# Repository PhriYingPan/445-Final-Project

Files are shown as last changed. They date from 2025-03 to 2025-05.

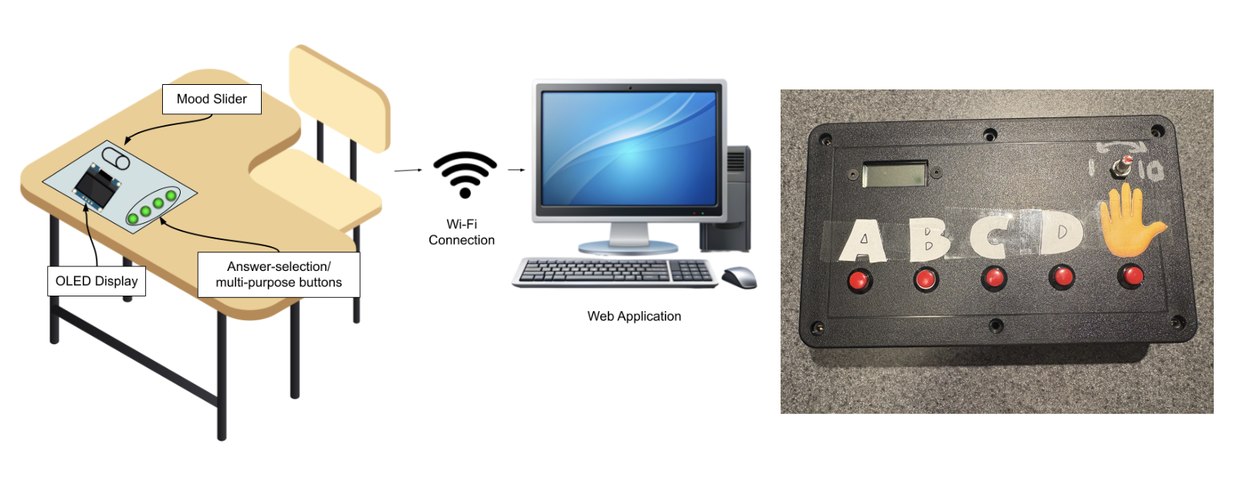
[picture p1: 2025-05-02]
visual_aid.png

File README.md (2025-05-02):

# Desk Aid Learning Device 

### Team Members

- [Aidan Johnston](https://github.com/AidanJ16)
- [Conan Pan](https://github.com/PhriYingPan)
- [Ethan Ge](https://github.com/ethange2)

## 1.1 Problem

In recent years, there has been a growing trend of integrating technology into schools. This trend has been accelerated by the lasting impacts of the Covid-19 pandemic and the continuous advancements in digital devices and tools. Schools across the nation have adopted computers, tablets, and virtual learning platforms to enhance education and increase accessibility in the pursuit of modernizing the classroom. While these technologies offer incredible benefits, they also introduce challenges, particularly in elementary school classrooms. 

One of the most critical problems is the effect screen time is having on students. By incorporating technological devices in classrooms, students are spreading prolonged periods interacting with screens. Studies have begun to highlight how this excessive screen time can lead to a severe lack of social skills, shorter attention spans, and higher frequencies of disruptions. These trends contribute to a less effective and unhealthy learning environment. Furthermore, studies are exploring connections between prolonged exposure to screens and decreases in mental and physical well-being. Therefore, in the pursuit of generating a more social, engaging, and nurturing environment for young students we propose the desk learning aid device.

## 1.2 Solution

The desk learning aid device will function through various buttons and a scroller connected to a customized PCB device. These buttons and the scroller will correspond to responding to polls/questions, comprehension checks, asking questions, and more. The device will communicate to an application that can be monitored by the teacher where they will receive real-time feedback. The teacher can have a better understanding of the student’s comprehension levels and be able to properly cater towards providing the students the most effective lesson. The purpose of this device would be to provide a cost-effective solution that can be set up at each student’s desk to promote a stronger and healthier learning environment for students. This differs from other options on the market due to easier set up because other options require you to create a question in order to receive a response, however, our device allows for many passive inputs including comprehension and other urgent needs. In addition, other portable solutions require students to buy each device individually costing them hundreds of dollars, but our solution only requires the purchase of a reusable RFID keycard that is cheap and easy to use.

# Visual Aid 
Screenshot 2025-05-02 at 2 36 59 PM

# Results

 - [Demo Video](https://drive.google.com/file/d/13fJDIUi9QKVj2l2KASiBSuiVs_a9EkWj/view?usp=sharing)
 - [Presentation](https://github.com/user-attachments/files/20017662/Desk.Aid.Learning.Device.Team.27.pptx)
 - [Design Document](https://github.com/user-attachments/files/20017668/445.Design.Document.3.pdf)

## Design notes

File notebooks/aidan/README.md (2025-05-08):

# Aidan Johnston's Lab Notebook – Desk Learning Aid Device

This notebook documents the comprehensive design, development, testing, and firmware implementation for the Desk Learning Aid Device. It particularly highlights my contributions to the customized PCB and subsystem integration.

---

## 2025-02-01 – Initial Project Direction

**Objectives:**

* Discussed the core project idea and goals with teammates and our TA, Kaiwen Cao.
* Explored engagement mechanisms suitable for classroom environments that avoid excessive screen time.

**Progress:**

* Proposed using a physical interaction system incorporating RFID-based student identification, button-based input, and a rotary encoder or potentiometer scroller.
* Envisioned a backend system supported by Firebase to relay data to a real-time web dashboard accessible to teachers.
* Sketched an initial block diagram representing all subsystems (power, microcontroller, interface, input, and RFID).

---

## 2025-02-14 – Finalize Project

**Objectives:**

* Solidify the overall architecture and prepare for the proposal review.

**Progress:**

* Finalized a refined block diagram detailing subsystem interactions.
* Designed initial device enclosures and mounting plans for discussion with the Machine Shop.
* Scheduled zoom meetings with elementary school teachers to ensure project alignment with classroom needs.
* Began outlining our project proposal for review by course instructors and TAs.

---

## 2025-02-23 – Initial PCB Design Part 1

**Objectives:**

* Begin translating conceptual design into manufacturable electronic schematics.

**Progress:**

* Created a rough draft schematic in KiCad featuring major components: ESP32-S3, push buttons, RFID, voltage regulators, and display interface.
* Assigned preliminary footprints to each component, focusing on pin mapping and layout constraints.

---

## 2025-03-05 – Initial PCB Design Part 2

**Objectives:**

* Convert schematic to a routed PCB design and initiate documentation.

**Progress:**

* Structured the PCB by subsystem (power, input, interface, RFID, microcontroller), allowing for intuitive routing.
* Assigned logical labels, visibility settings, and ground stitching to reduce EMI.
* Helped draft the design documentation section related to PCB layout, component selection, and routing decisions.

---

## 2025-03-13 – Initial PCB Design Part 3

**Objectives:**

* Submit the initial board to PCBWay.

**Progress:**

* Used KiCad's Design Rule Checker to identify and correct errors.
* Submitted and passed PCBWay's manufacturing audit.
* Submitted the design to our TA as apart of the Second Round Orders.

---

## 2025-03-24 – Updated PCB Design Part 1

**Objectives:**

* Evaluate prior board and fix discovered issues.

**Challenges:**

* Incorrect footprint for buck-boost converter (TPS63001).
* Programming circuit for ESP32-S3 not compatible with UART flashing.
* Incorrect footprints for push buttons, inverters, and LCD connector.

**Solutions:**

* Corrected all footprints by referencing datasheets and comparing to KiCad libraries.
* Revised programming method to use USB-to-UART dongle with GND, TX, RX, DTR, RTS lines.
* Rechecked layout and connections for consistency and ease of access.

---

## 2025-03-31 – Updated PCB Design Part 2

**Objectives:**

* Submit improved board design.

**Progress:**

* Rerouted traces and updated board labeling.
* Verified footprint clearances and pad sizes.
* Used KiCad's Design Rule Checker to identify and correct errors.
* Submitted and passed PCBWay's manufacturing audit.
* Submitted the design to our TA as apart of the Third Round Orders.

---

## 2025-04-17 – Hardware Testing

**Objectives:**

* Validate the power subsystem and ESP32 flashing.

**Progress:**

* Measured 3.27V at ESP32 input pin (target: 3.3V).
* Identified error in design: resistor R13 (pull-down) interfered with programming, removed it to enable successful flashing.

---

## 2025-04-29 – Software Testing

**Objectives:**

* Program LCD to verify interface subsystem.

**Progress:**

* Initial attempts to display characters failed.
* Identified reversed SPI pin assignments to LCD: MOSI needed to connect to SID, and MISO to SOD.
* Recognized need for external RST circuit for reliable LCD initialization.

---
## Verification Procedures

**1. DRC Testing**

* All boards verified using KiCad’s DRC.
* Ensured clearance, trace width, and via rules met manufacturing constraints.

**2. Continuity Testing**

* Verified pin-to-pin connections and ground continuity.
* Used multimeter beep function across all critical signal lines.

**3. Power Integrity Test**

* Verified output voltages at ESP32 (3.27V), LCD, and RFID reader.
* Measured battery charge and boost output stability under load.

**4. Boot and Flash Test**

* Helped successfully flash test program using esptool.py.

**5. Input Test**

* Button presses triggered correct GPIO interrupts.
* Potentiometer yielded stable ADC values.

---

## Bibliographic References

1. Espressif Systems. (2023). *ESP32-S3-WROOM-1 & ESP32-S3-WROOM-1U Datasheet*.
2. Firebase. (2024). *Realtime Database Documentation*.
3. ELECTRONIC ASSEMBLY GmbH. (n.d.). *DOGS104E Graphic Display Module*.
4. Texas Instruments. (2008). *TPS63000 High-Efficiency Buck-Boost Converter Datasheet*.
5. TOPPOWER. (2023). *TP4057 Battery Charging and Protection IC Datasheet*.
6. Texas Instruments. (2002). *SN74LS05 Hex Inverter Datasheet*.
7. NXP Semiconductors. (2018). *PN512 NFC Reader IC Datasheet*.
8. Adafruit. (n.d.). *Push Button #492*.
9. Bourns Inc. (2020). *PDB181 Series Potentiometer Datasheet*.
10. IEEE. (2023). *IEEE Code of Ethics*.
11. U8G2 Library Documentation. (2024). *Monochrome Graphics Library for Embedded Devices*.

---

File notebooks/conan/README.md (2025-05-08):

# Conan Pan's Lab Notebook – Desk Learning Aid Device

This notebook documents the design, development, and testing efforts for the Desk Learning Aid Device, specifically focusing on the web application and firmware components I was responsible for.

---

## 2025-02-01 – Initial Project Direction

**Objectives:**
- Discussed core project idea with teammates and TA.
- Brainstormed solutions for capturing student engagement without screens.

**Progress:**
- Proposed idea of combining physical desk input (RFID, buttons, scroller) with a teacher-facing web dashboard.
- Identified potential microcontroller (ESP32-S3) and real-time database (Firebase).
- Sketched initial system block diagram.

---

## 2025-02-14 – WiFi Communication Plan

**Objectives:**
- Finalize communication protocol between ESP32 and Web App.

**Progress:**
- Decided to send data from ESP32 → Web App via Wifi, with ESP32 acting as Wifi server.
- Drafted JSON data schema:
```json
{
  "timestamp": 1712159000000,
  "rfid": "04A3C2",
  "emotion": 7,
  "selectedAnswer": "B",
  "question": "Which fraction is smallest?",
  "subject": "Math",
  "correctAnswer": "C",
  "isCorrect": false
}
```

---

## 2025-03-05 – Breadboard Prototype

**Objectives:**
- Demonstrate basic functionality with ESP32-S3 on breadboard.

**Progress:**
- Wired 5 push buttons, 1 rotary scroller, RFID reader.
- Developed C firmware (`hello_world_main.c`) to:
  - Debounce button presses.
  - Sample potentiometer input via ADC1_CH8.
  - Send responses to Firebase via HTTPS.
- Verified WiFi round-trip latency under 100ms and analog scaling of emotion (1–10).

---

## 2025-03-13 – Dashboard Development

**Objectives:**
- Build interactive frontend dashboard for teachers.

**Progress:**
- Implemented `StudentDashboard.jsx` in React:
  - Displays correctness history, emotion bar, and raise-hand notifications.
  - Allows teacher to push prompts to Firebase.
  - Visualizes subject performance using Chart.js.
- Integrated Firebase Realtime Database and onValue listeners.

Screenshot 2025-05-01 at 3 58 56 PM

Screenshot 2025-05-01 at 3 59 00 PM

Screenshot 2025-05-01 at 4 01 00 PM

---

## 2025-03-24 – Tolerance and Signal Analysis

**Objectives:**
- Evaluate WiFi reliability in classroom conditions.

**Equations:**
Using log-distance path loss model:

PL(d) = PL(d₀) + 10n log₁₀(d/d₀)

PL(10 m) = 40 dB + 10 × 2.7 × log₁₀(10) = 67 dB

ESP32 TX Power: +4 dBm  
WiFi Sensitivity: –90 dBm  
→ Received power = –63 dBm → Link margin = 27 dB

**Result:** WiFi communication is reliable across a 10-meter classroom with expected margin.

---

## 2025-04-29 – Final Integration and Debugging

**Objectives:**
- Complete testing loop from physical input to UI.
- Fix Firebase timestamp issues.

**Progress:**
- Verified timestamps now use `time(NULL) * 1000` for accurate ms precision.
- Fixed JSON encoding and logging in Firebase.
- Coordinated with hardware team to validate ESP32 behavior on PCB power-up.

Screenshot 2025-05-01 at 4 06 28 PM

Screenshot 2025-05-01 at 4 23 56 PM

**Remaining Tasks:**
- Final UI polish (labels, error states).
- Secure Firebase rules and access tokens.
- Conduct classroom-scale demo.

---

## Bibliographic References

1. [ESP32-S3-WROOM Datasheet](https://www.espressif.com/sites/default/files/documentation/esp32-s3-wroom-1_datasheet_en.pdf)  
2. [Firebase Realtime Database Docs](https://firebase.google.com/docs/database)  
3. [Chart.js Documentation](https://www.chartjs.org/docs/)  
4. [Adafruit Push Button #492](https://www.adafruit.com/product/492)  
5. [Bourns PDB181 Datasheet](https://www.bourns.com/docs/Product-Datasheets/pdb181.pdf)

---

## Notes

- All application code (ESP32 firmware and web dashboard) was written by me.
- GitHub repo includes full commit history and test data.

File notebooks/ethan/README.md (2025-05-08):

# Ethan Ge's Lab Notebook – Desk Learning Aid Device

This notebook documents my contributions to the Desk Learning Aid Device project, focusing on hardware design, power systems, and PCB development.

---

## 2025-02-01– Initial Hardware Architecture

**Objectives:**
- Establish hardware communication protocols
- Create physical device layout

**Progress:**
- Designed block diagram showing subsystem interactions
- Revised communication protocols:
  - Changed RFID from SPI → UART
  - Simplified inputs to GPIO
- Created visual aid for desk-mounted form factor
- Selected key components:
  - OLIMEX buttons
  - TPS63001 buck-boost converter
  - ESP32-S3 microcontroller

Block Diagram

---

## 2025-02-14– Power System Design

**Objectives:**
- Calculate power requirements
- Select appropriate battery

**Calculations:**
```
Total Power Draw = (3.3V * 100mA) / 90% efficiency = 0.36W
Battery Capacity Needed = 0.36W * 8h / 3.7V = 1086mAh
```

**Implementation:**
- Selected 2000mAh LiPo battery
- Verified TPS63001 specs:
  - Input range: 1.8-5.5V
  - Output: 3.3V ±2%
  - Peak efficiency: 96%

**Test Plan:**
| Requirement | Verification Method |
|---|---|
| 8h runtime @ 3.0V+ | Continuous operation test |
| Stable 3.3V output | Variable load testing |

---

## 2025-03-05 – PCB Development

**Objectives:**
- Finalize PCB layout
- Address design flaws

**Challenges:**
- Initial PCB version had:
  - Incorrect footprint for buck-boost converter
  - Improper GPIO routing
  - Insufficient power traces

**Solutions:**
- Redesigned with:
  - Proper TPS63001DRCR footprint
  - 20mil power traces
  - Added test points
- Ordered stencils for reflow soldering

PCB Layout

---

## 2025-03-13 – Hardware Testing

**Objectives:**
- Validate power subsystem
- Test component integration

**Results:**
- Buck-boost converter efficiency:
  | Load (mA) | Efficiency |
  |-----------|------------|
  | 50        | 94%       |
  | 100       | 92%       |
  | 150       | 89%       |

- Battery discharge test:
  - 8h continuous operation
  - Final voltage: 3.27V (meets requirement)
 
Test Results

**Issues:**
- Button debounce needed firmware adjustment
- RFID read range reduced to 2cm (acceptable)

---

## 2025-03-24 – System Integration

**Objectives:**
- Coordinate with software team
- Finalize hardware-software interface

**Progress:**
- Finalized firmware for ESP32
- Verified end-to-end operation:
  - Physical input → ESP32 → Web dashboard
  - Average latency: 120ms

**Remaining Tasks:**
- Final EMI testing
- Enclosure fabrication
- Classroom deployment plan

---

## Bibliographic References

1. [ESP32-S3 Datasheet](https://www.espressif.com/sites/default/files/documentation/esp32-s3_datasheet_en.pdf)
2. [TPS63001 Technical Reference](https://www.ti.com/lit/ds/symlink/tps63001.pdf)
3. [LiPo Battery Characteristics](https://batteryuniversity.com/article/bu-205-types-of-lithium-ion)
4. [PCB Design Guidelines](https://www.analog.com/en/analog-dialogue/articles/pcb-layout-techniques.html)

---

## Notes

- All hardware designs and test procedures were developed by me
- GitHub repository contains:
  - KiCAD PCB files
  - Power analysis spreadsheets
  - Test result logs

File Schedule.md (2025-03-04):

# 445-Final-Project

Schedule: 

Week
Date
Task 
1
2/26 - 3/3
- Finalize architecture & system design (Block Diagram, High-Level Requirements)
- Select and order key components for the first prototype
- Prepare for Design Document submission

2
3/4 - 3/10
- Design Document Due (3/3)
- First Round PCBWay Order (Must Pass Audit by Today, 3/3)
- Start initial breadboard prototyping and circuit validation
- Develop firmware skeleton for microcontroller functionality

3
3/11 - 3/17
- Breadboard Demonstration with Instructor & TA (3/10)
- Test basic component functionality (buttons, RFID reader, OLED display)
- Validate Bluetooth Low Energy (BLE) communication with web app
- Second Round PCBWay Order (Must Pass Audit by Today, 3/10)

4
3/18 - 3/24
No work scheduled

5
3/25 - 3/31
- Refine PCB design and address any issues from breadboard testing
- Test battery power consumption and efficiency
- Start developing microcontroller drivers for all subsystems

6
4/1 - 4/7
- Third Round PCBWay Order (Must Pass Audit by Today, 3/31)
- Individual Progress Reports Due (3/31)
- Assemble first PCB and perform functional testing
- Debug BLE communication and integrate with the web application

7
4/8 - 4/14
- Fourth Round PCBWay Order (Must Pass Audit by Today, 4/7)
- Begin full system integration and initial software debugging
- Conduct power management tests and optimize battery life

8
4/15 - 4/21
- Team Contract Assessment Due (4/14)
- Start testing real-time classroom interactions with the web application
- Optimize PCB and firmware for responsiveness and low latency

9
4/22 - 4/28
- Mock Demo During Weekly TA Meeting
- Verify all high-level requirements are met
- Debug remaining issues in hardware/software integration

10
4/29 - 5/5
- Final Demo with Instructor & TAs (4/28)
- Conduct system-wide performance testing
- Prepare presentation materials for final submission

11
5/6 - 5/12
- Final Presentation with Instructor & TAs (5/5)
- Final Papers Due (5/5)
- Lab Notebook Due (5/5)
- Award Ceremony (5/5)
- Perform final documentation and lab checkout

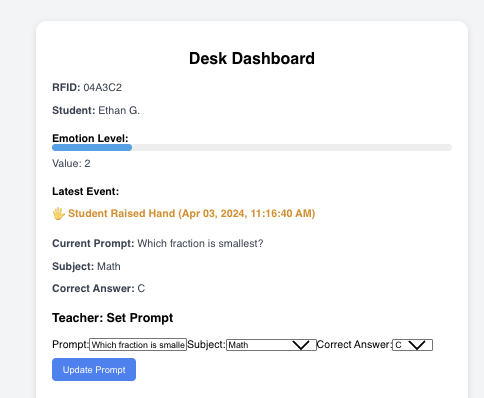
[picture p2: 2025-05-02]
notebooks/conan/dashboard_1.png

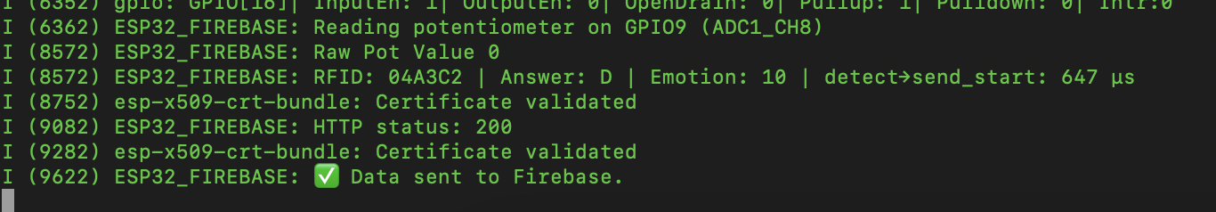
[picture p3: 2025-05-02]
notebooks/conan/button_latency.png

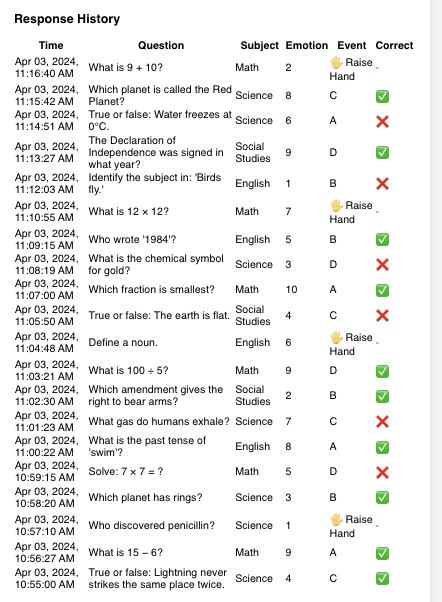
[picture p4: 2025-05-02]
notebooks/conan/dashboard_2.png

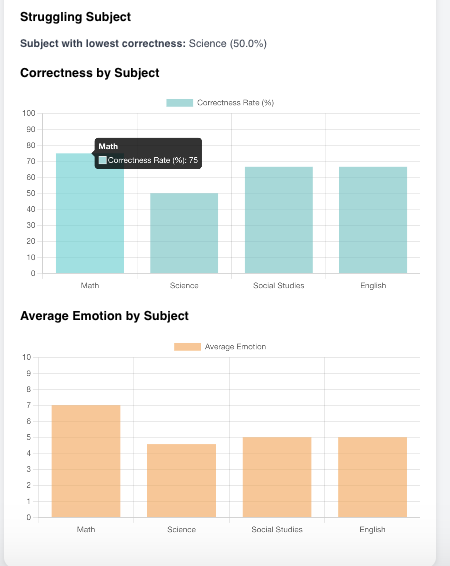
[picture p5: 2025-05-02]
notebooks/conan/dashboard_3.png

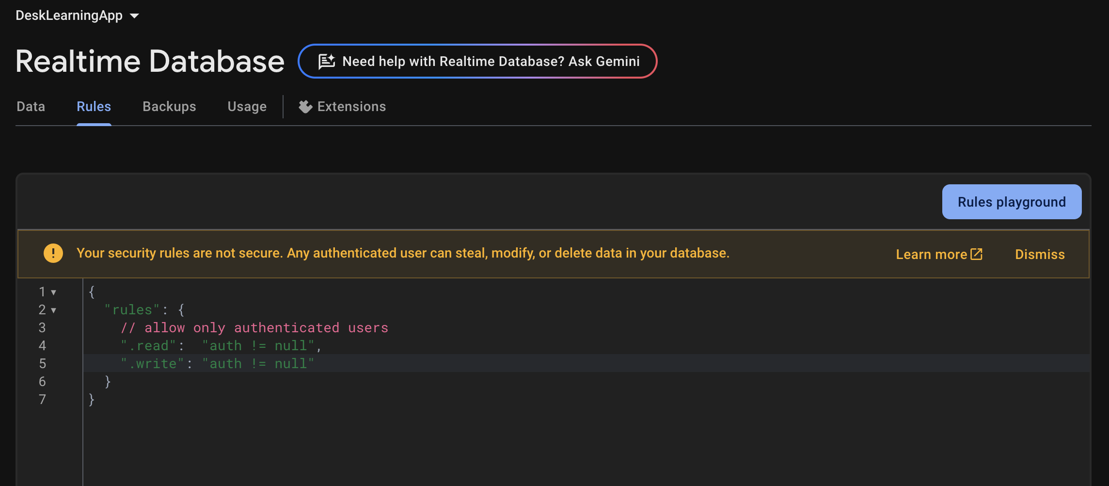
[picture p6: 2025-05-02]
notebooks/conan/firebase_auth.png

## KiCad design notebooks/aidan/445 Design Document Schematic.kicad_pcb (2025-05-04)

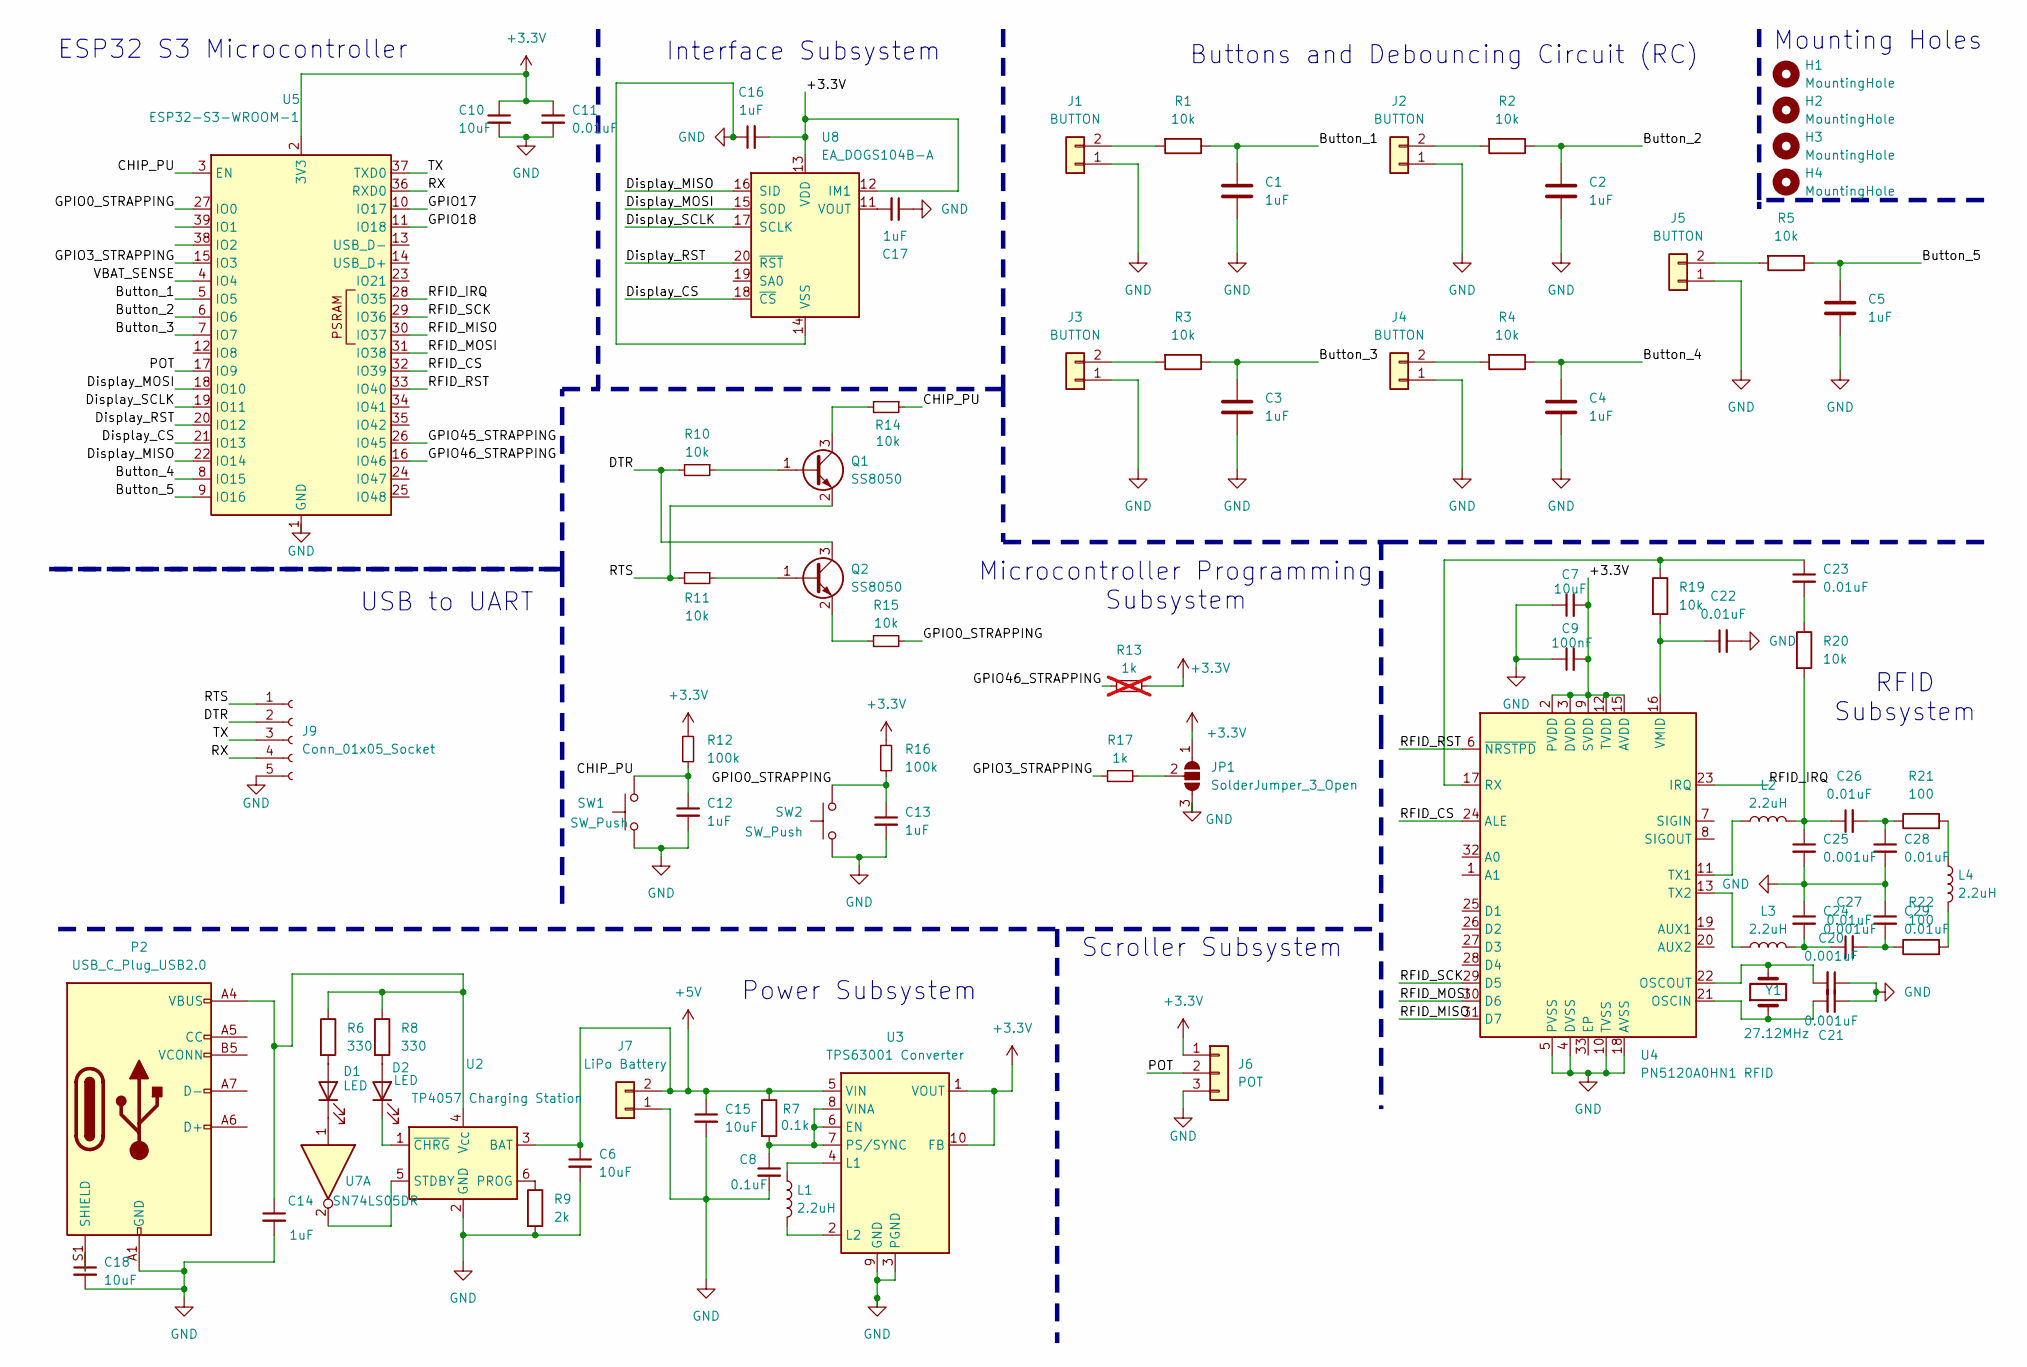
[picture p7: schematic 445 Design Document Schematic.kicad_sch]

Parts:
C1, C2, C3, C4, C5, C12, C13, C14, C16, C17: 1uF; C_0805_2012Metric_Pad1.18x1.45mm_HandSolder
C6, C7, C10, C15, C18: 10uF; C_0805_2012Metric_Pad1.18x1.45mm_HandSolder
C8: 0.1uF; C_0805_2012Metric_Pad1.18x1.45mm_HandSolder
C9: 100nF; C_0805_2012Metric_Pad1.18x1.45mm_HandSolder
C11, C22, C23, C26, C27, C28, C29: 0.01uF; C_0805_2012Metric_Pad1.18x1.45mm_HandSolder
C20, C21, C24, C25: 0.001uF; C_0805_2012Metric_Pad1.18x1.45mm_HandSolder
D1, D2: LED; Molex_KK-254_AE-6410-02A_1x02_P2.54mm_Vertical
H1, H2, H3, H4: MountingHole; MountingHole_3.2mm_M3
J1, J2, J3, J4, J5: BUTTON; Molex_KK-254_AE-6410-02A_1x02_P2.54mm_Vertical
J6: POT; Molex_KK-254_AE-6410-03A_1x03_P2.54mm_Vertical
J7: LiPo Battery; Molex_KK-254_AE-6410-02A_1x02_P2.54mm_Vertical
J9: Conn_01x05_Socket; PinHeader_1x05_P2.54mm_Vertical
JP1: SolderJumper_3_Open; SolderJumper-3_P1.3mm_Open_Pad1.0x1.5mm
L1, L2, L3, L4: 2.2uH; L_0805_2012Metric_Pad1.15x1.40mm_HandSolder
P2: USB_C_Plug_USB2.0; USB_C_Receptacle_JAE_DX07S016JA1R1500
Q1, Q2: SS8050; SOT-23
R1, R2, R3, R4, R5, R10, R11, R14, R15, R19, R20: 10k; R_0805_2012Metric_Pad1.20x1.40mm_HandSolder
R6, R8: 330; R_0805_2012Metric_Pad1.20x1.40mm_HandSolder
R7: 0.1k; R_0805_2012Metric_Pad1.20x1.40mm_HandSolder
R9: 2k; R_0805_2012Metric_Pad1.20x1.40mm_HandSolder
R12, R16: 100k; R_0805_2012Metric_Pad1.20x1.40mm_HandSolder
R13: 1k; R_0805_2012Metric_Pad1.20x1.40mm_HandSolder; not fitted
R17: 1k; R_0805_2012Metric_Pad1.20x1.40mm_HandSolder
R21, R22: 100; R_0805_2012Metric_Pad1.20x1.40mm_HandSolder
SW1, SW2: SW_Push; SW_PUSH_6mm
U2: TP4057 Charging Station; TSOT-23-6
U3: TPS63001 Converter; Texas_DRC0010J_ThermalVias
U4: PN5120A0HN1 RFID; HVQFN-32-1EP_5x5mm_P0.5mm_EP3.1x3.1mm
U5: ESP32-S3-WROOM-1
U7: SN74LS05DR; DIP-14_W7.62mm
U8: EA_DOGS104B-A; EA_DOGS104X-A
Y1: 27.12MHz; Crystal_SMD_5032-4Pin_5.0x3.2mm

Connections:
+3.3V: C7.2, C9.2, C10.1, C11.1, C16.2, J6.1, JP1.1 (A), R12.1, R13.1, R16.1, U3.1 (VOUT), U3.10 (FB), U4.2 (PVDD), U4.3 (DVDD), U4.9 (SVDD), U4.12 (TVDD), U4.15 (AVDD), U5.2 (3V3), U8.12 (IM1), U8.13 (VDD)
+5V: C6.1, C15.1, J7.2, R7.1, U2.3 (BAT), U3.5 (VIN)
/Button_1: C1.1, R1.1, U5.5 (IO5)
/Button_2: C2.1, R2.1, U5.6 (IO6)
/Button_3: C3.1, R3.1, U5.7 (IO7)
/Button_4: C4.1, R4.1, U5.8 (IO15)
/Button_5: C5.1, R5.1, U5.9 (IO16)
/CHIP_PU: C12.1, R12.2, R14.1, SW1.2, U5.3 (EN)
/DTR: J9.2, Q2.3 (C), R10.2
/Display_CS: U5.21 (IO13), U8.18 (~CS)
/Display_MISO: U5.22 (IO14), U8.16 (SID)
/Display_MOSI: U5.18 (IO10), U8.15 (SOD)
/Display_RST: U5.20 (IO12), U8.20 (~RST)
/Display_SCLK: U5.19 (IO11), U8.17 (SCLK)
/GPIO0_STRAPPING: C13.1, R15.2, R16.2, SW2.2, U5.27 (IO0)
/GPIO3_STRAPPING: R17.1, U5.15 (IO3)
/GPIO17: U5.10 (IO17)
/GPIO18: U5.11 (IO18)
/GPIO45_STRAPPING: U5.26 (IO45)
/GPIO46_STRAPPING: R13.2, U5.16 (IO46)
/POT: J6.2, U5.17 (IO9)
/RFID_CS: U4.24 (ALE), U5.32 (IO39)
/RFID_IRQ: U4.23 (IRQ), U5.28 (IO35)
/RFID_MISO: U4.31 (D7), U5.30 (IO37)
/RFID_MOSI: U4.30 (D6), U5.31 (IO38)
/RFID_RST: U4.6 (~NRSTPD), U5.33 (IO40)
/RFID_SCK: U4.29 (D5), U5.29 (IO36)
/RTS: J9.1, Q1.2 (E), R11.2
/RX: J9.4, U5.36 (RXD0)
/TX: J9.3, U5.37 (TXD0)
/VBAT_SENSE: U5.4 (IO4)
GND: C1.2, C2.2, C3.2, C4.2, C5.2, C6.2, C7.1, C8.2, C9.1, C10.2, C11.2, C12.2, C13.2, C14.2, C15.2, C16.1, C17.1, C18.2, C20.1, C21.1, C22.2, C24.1, C25.2, C28.2, C29.1, J1.1, J2.1, J3.1, J4.1, J5.1, J6.3, J7.1, J9.5, JP1.3 (B), P2.A1 (GND), P2.A12 (GND), P2.B1 (GND), P2.B12 (GND), R9.2, SW1.1, SW2.1, U2.2 (GND), U3.3 (PGND), U3.9 (GND), U3.11 (PGND), U4.4 (DVSS), U4.5 (PVSS), U4.10 (TVSS), U4.14 (TVSS), U4.18 (AVSS), U5.1 (GND), U5.40 (GND), U5.41 (GND), U8.14 (VSS)
unnamed: C23.2, R20.1
unnamed: C24.2, C27.1, L3.2
unnamed: C25.1, C26.1, L2.2, R20.2
unnamed: C26.2, C28.1, R21.1
unnamed: C27.2, C29.2, R22.1
unnamed: D1.2 (A), R6.2
unnamed: D1.1 (K), U7.1
unnamed: D2.2 (A), R8.2
unnamed: D2.1 (K), U2.1 (~CHRG)
unnamed: J1.2, R1.2
unnamed: J2.2, R2.2
unnamed: J3.2, R3.2
unnamed: J4.2, R4.2
unnamed: J5.2, R5.2
unnamed: JP1.2 (C), R17.2
unnamed: L4.1, R21.2
unnamed: L4.2, R22.2
unnamed: C18.1, P2.S1 (SHIELD)
unnamed: Q1.1 (B), R10.1
unnamed: Q1.3 (C), R14.2
unnamed: Q2.1 (B), R11.1
unnamed: Q2.2 (E), R15.1
unnamed: R9.1, U2.6 (PROG)
unnamed: U2.5 (STDBY), U7.2
unnamed: C14.1, P2.A4 (VBUS), P2.A9 (VBUS), P2.B4 (VBUS), P2.B9 (VBUS), R6.1, R8.1, U2.4 (V_{CC})
unnamed: C8.1, R7.2, U3.6 (EN), U3.7 (PS/SYNC), U3.8 (VINA)
unnamed: L1.1, U3.4 (L1)
unnamed: L1.2, U3.2 (L2)
unnamed: C21.2, U4.21 (OSCIN), Y1.1
unnamed: C20.2, U4.22 (OSCOUT), Y1.2
unnamed: C23.1, R19.1, U4.17 (RX)
unnamed: L2.1, U4.11 (TX1)
unnamed: L3.1, U4.13 (TX2)
unnamed: C22.1, R19.2, U4.16 (VMID)
unnamed: C17.2, U8.11 (VOUT)

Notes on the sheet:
USB to UART
Interface Subsystem
Power Subsystem
ESP32 S3 Microcontroller
Scroller Subsystem
Buttons and Debouncing Circuit (RC)
Microcontroller Programming Subsystem
RFID Subsystem
Mounting Holes

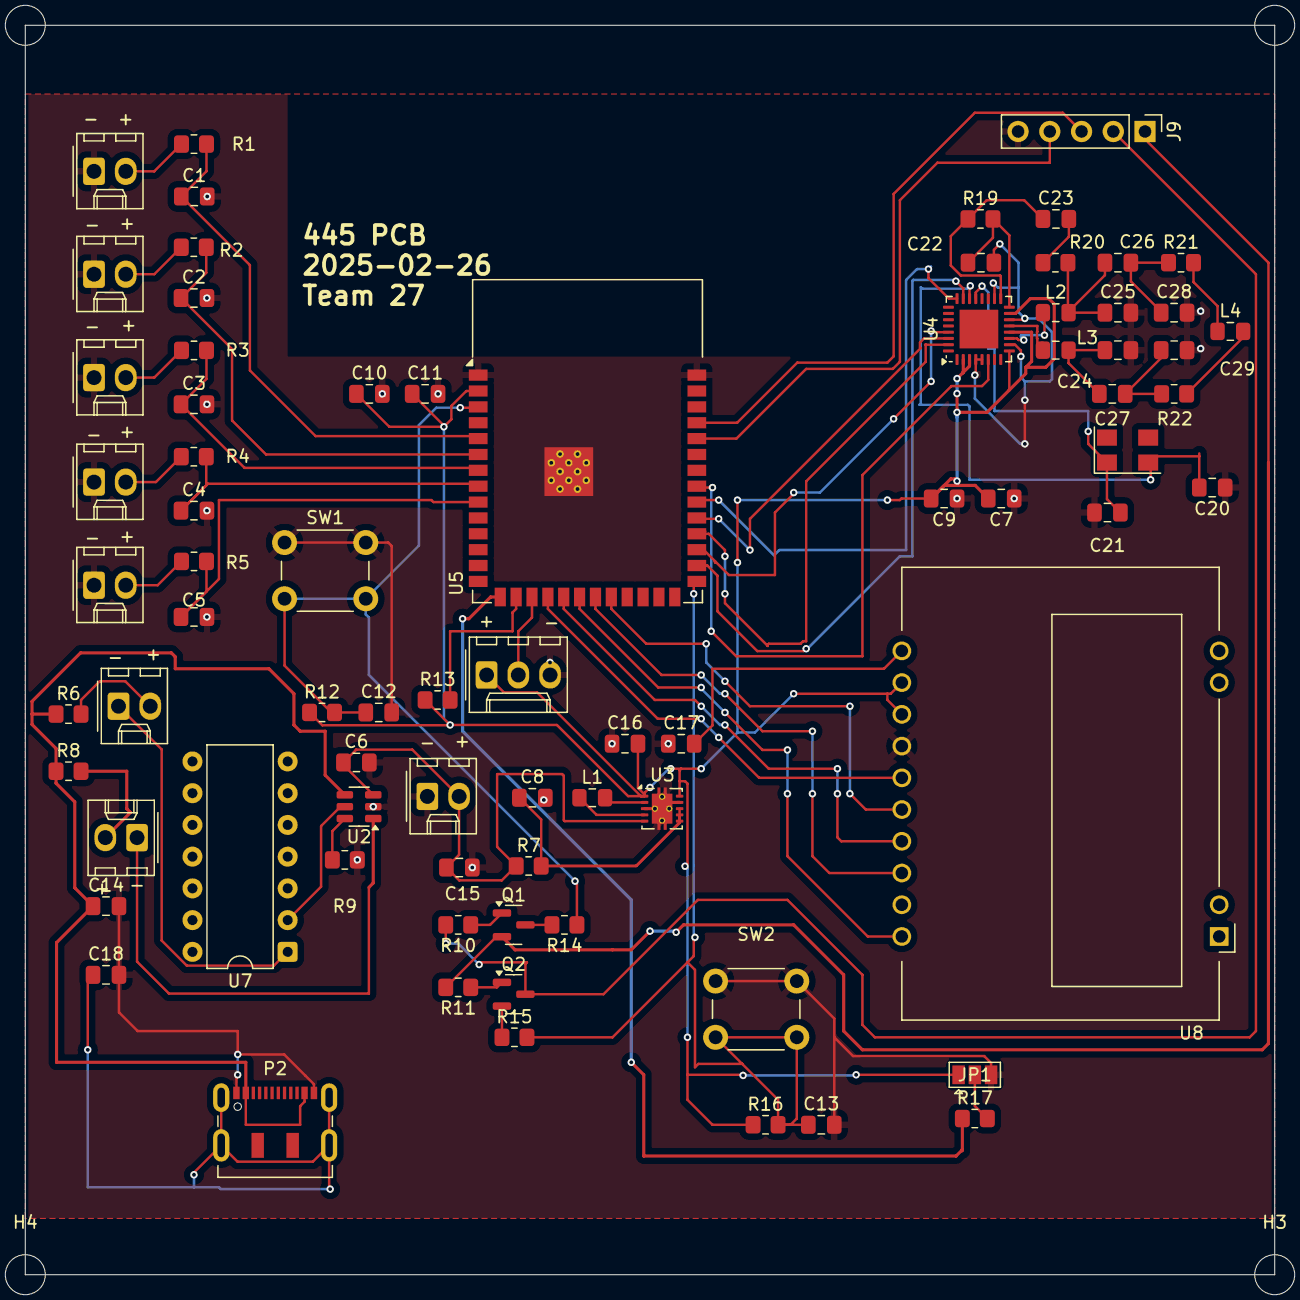
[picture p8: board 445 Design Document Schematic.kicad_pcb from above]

Board: 2 copper layers, 100.0 x 100.0 mm, 80 parts (0 on the bottom side), 63 nets.

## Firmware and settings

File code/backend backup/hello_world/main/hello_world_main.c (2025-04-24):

#include <stdio.h>
#include <string.h>
#include <time.h>

#include "freertos/FreeRTOS.h"
#include "freertos/task.h"
#include "freertos/event_groups.h"
#include "driver/gpio.h"
#include "driver/adc.h"
#include "driver/spi_master.h"
#include "esp_log.h"
#include "esp_http_client.h"
#include "esp_wifi.h"
#include "nvs_flash.h"
#include "esp_event.h"
#include "esp_netif.h"
#include "cJSON.h"
#include "esp_crt_bundle.h"

#include "esp_sntp.h"

// #include <u8g2.h>
// #include "u8g2_esp32_hal.h"


/* -------------------------------------------------------------------------- */
/*  Wi‑Fi credentials                                                         */
/* -------------------------------------------------------------------------- */
// #define WIFI_SSID "NETGEAR34"
// #define WIFI_PASS "silentspider842"
#define WIFI_SSID "Conan's iPhone (2)"
#define WIFI_PASS "wec6n3340tvv"

/* -------------------------------------------------------------------------- */
/*  Firebase Realtime‑DB                                                      */
/* -------------------------------------------------------------------------- */
#define FIREBASE_HOST "https://desklearningapp-default-rtdb.firebaseio.com"  /* no trailing slash */
#define FIREBASE_CURRENT_PROMPT FIREBASE_HOST "/currentPrompt.json"          /* GET  */


#define FIREBASE_RESPONSES_PATH  FIREBASE_HOST "/students/%s/responses.json" /* POST */

/* -------------------------------------------------------------------------- */
/*  Application constants                                                     */
/* -------------------------------------------------------------------------- */
#define STUDENT_ID "student1"
#define STUDENT_NAME "Ethan Ge"

#define RFID_TAG   "04A3C2"

/*  Button GPIOs – avoid 6–11 (SPI‑flash) and 34–39 (input‑only)              */
#define BTN_A 5
#define BTN_B 6
#define BTN_C 7
#define BTN_D 15
#define BTN_E 16

static const char *TAG = "ESP32_FIREBASE";

// CORRECT: ADC1_CHANNEL_8 is on GPIO 9
#define POT_CHANNEL ADC1_CHANNEL_8



static void obtain_time(void)
{
    /* 1-line setup: poll “pool.ntp.org” every 60 s (default) */
    sntp_setoperatingmode(SNTP_OPMODE_POLL);
    sntp_setservername(0, "pool.ntp.org");
    esp_sntp_init();

    /* block (max ~10 s) until we get a sane epoch */
    time_t now = 0;
    struct tm tm = {0};
    int retry = 0;
    const int max_retry = 20;
    while (tm.tm_year < (2024 - 1900) && ++retry < max_retry) {
        ESP_LOGI(TAG, "⏳ Waiting for NTP (%d/%d)…", retry, max_retry);
        vTaskDelay(pdMS_TO_TICKS(1000));
        time(&now);
        localtime_r(&now, &tm);
    }
    if (tm.tm_year < (2024 - 1900)) {
        ESP_LOGW(TAG, "⚠️  NTP sync failed—timestamps will be wrong");
    } else {
        ESP_LOGI(TAG, "✅ Time set: %s", asctime(&tm));
    }
}


/* -------------------------------------------------------------------------- */
/*  Prompt structure                                                          */
/* -------------------------------------------------------------------------- */
typedef struct {
    char question[128];
    char subject[32];
    char correctAnswer[4];
} Prompt;


/* =============================  NEW: LCD DEFS  ============================ */
#define PIN_MOSI 10    // DIN on the DOGS104
#define PIN_SCLK 11    // CLK
#define PIN_CS   13    // CS#
#define PIN_DC   14    // SA0 / D-C#
#define PIN_RST  12    // RST#

static const char *LCD_TAG = "DOGS104-U8g2";

// static spi_device_handle_t lcd;
// // static const char *LCD_TAG = "LCD";


// /* 5×8 font taken from classic PC BIOS (only printable 0x20–0x7F). */
// static const uint8_t font5x8[96][5] = {
//     {0x00,0x00,0x00,0x00,0x00}, /* 0x20 ' ' */
//     {0x00,0x00,0x5f,0x00,0x00}, /* 0x21 '!' */
//     {0x00,0x07,0x00,0x07,0x00}, /* 0x22 '"' */
//     {0x14,0x7f,0x14,0x7f,0x14}, /* 0x23 '#' */
//     {0x24,0x2a,0x7f,0x2a,0x12}, /* 0x24 '$' */
//     {0x23,0x13,0x08,0x64,0x62}, /* 0x25 '%' */
//     {0x36,0x49,0x55,0x22,0x50}, /* 0x26 '&' */
//     {0x00,0x05,0x03,0x00,0x00}, /* 0x27 ''' */
//     {0x00,0x1c,0x22,0x41,0x00}, /* 0x28 '(' */
//     {0x00,0x41,0x22,0x1c,0x00}, /* 0x29 ')' */
//     {0x14,0x08,0x3e,0x08,0x14}, /* 0x2A '*' */
//     {0x08,0x08,0x3e,0x08,0x08}, /* 0x2B '+' */
//     {0x00,0x50,0x30,0x00,0x00}, /* 0x2C ',' */
//     {0x08,0x08,0x08,0x08,0x08}, /* 0x2D '-' */
//     {0x00,0x60,0x60,0x00,0x00}, /* 0x2E '.' */
//     {0x20,0x10,0x08,0x04,0x02}, /* 0x2F '/' */
//     {0x3e,0x51,0x49,0x45,0x3e}, /* 0x30 '0' */
//     {0x00,0x42,0x7f,0x40,0x00}, /* 0x31 '1' */
//     {0x42,0x61,0x51,0x49,0x46}, /* 0x32 '2' */
//     {0x21,0x41,0x45,0x4b,0x31}, /* 0x33 '3' */
//     {0x18,0x14,0x12,0x7f,0x10}, /* 0x34 '4' */
//     {0x27,0x45,0x45,0x45,0x39}, /* 0x35 '5' */
//     {0x3c,0x4a,0x49,0x49,0x30}, /* 0x36 '6' */
//     {0x01,0x71,0x09,0x05,0x03}, /* 0x37 '7' */
//     {0x36,0x49,0x49,0x49,0x36}, /* 0x38 '8' */
//     {0x06,0x49,0x49,0x29,0x1e}, /* 0x39 '9' */
//     {0x00,0x36,0x36,0x00,0x00}, /* 0x3A ':' */
//     {0x00,0x56,0x36,0x00,0x00}, /* 0x3B ';' */
//     {0x08,0x14,0x22,0x41,0x00}, /* 0x3C '<' */
//     {0x14,0x14,0x14,0x14,0x14}, /* 0x3D '=' */
//     {0x00,0x41,0x22,0x14,0x08}, /* 0x3E '>' */
//     {0x02,0x01,0x51,0x09,0x06}, /* 0x3F '?' */
//     {0x32,0x49,0x79,0x41,0x3e}, /* 0x40 '@' */
//     {0x7e,0x11,0x11,0x11,0x7e}, /* 0x41 'A' */
//     {0x7f,0x49,0x49,0x49,0x36}, /* 0x42 'B' */
//     {0x3e,0x41,0x41,0x41,0x22}, /* 0x43 'C' */
//     {0x7f,0x41,0x41,0x22,0x1c}, /* 0x44 'D' */
//     {0x7f,0x49,0x49,0x49,0x41}, /* 0x45 'E' */
//     {0x7f,0x09,0x09,0x09,0x01}, /* 0x46 'F' */
//     {0x3e,0x41,0x49,0x49,0x7a}, /* 0x47 'G' */
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
//     {0x00,0x00,0x00,0x00,0x00}  /* 0x7F (DEL) */
// };

// /* --------------------- low‑level LCD helpers ------------------------------ */
// static inline void lcd_dc_low(void)  { gpio_set_level(LCD_DC, 0); }
// static inline void lcd_dc_high(void) { gpio_set_level(LCD_DC, 1); }



// static void lcd_cmd(uint8_t c)
// {
//     lcd_dc_low();
//     spi_transaction_t t = {.length = 8, .tx_buffer = &c};
//     spi_device_transmit(lcd, &t);
// }

// static void lcd_set_contrast(uint8_t reg_ratio, uint8_t volume)
// /* reg_ratio = 0x20–0x27 , volume = 0x00–0x3F */
// {
//     lcd_cmd(reg_ratio);        // coarse
//     lcd_cmd(0x81);             // electronic volume command
//     lcd_cmd(volume);           // fine
// }

// static void lcd_data(const uint8_t *d, size_t n)
// {
//     lcd_dc_high();
//     spi_transaction_t t = {.length = n * 8, .tx_buffer = d};
//     spi_device_transmit(lcd, &t);
// }

// static void lcd_set_addr(uint8_t page, uint8_t col)
// {
//     lcd_cmd(0xB0 | (page & 0x0F));
//     lcd_cmd(0x10 | (col >> 4));
//     lcd_cmd(0x00 | (col & 0x0F));
// }

// static void lcd_clear(void)
// {
//     uint8_t blank[104] = {0};
//     for (uint8_t p = 0; p < 8; ++p) {
//         lcd_set_addr(p, 0);
//         lcd_data(blank, sizeof(blank));
//     }
// }

// static void draw_char(uint8_t page, uint8_t col, char ch)
// {
//     if (ch < 0x20 || ch > 0x7F) ch = '?';
//     lcd_set_addr(page, col);
//     lcd_data(font5x8[ch - 0x20], 5);
//     uint8_t gap = 0; lcd_data(&gap, 1);
// }

// static void draw_str(uint8_t page, const char *s)
// {
//     uint8_t col = 0;
//     while (*s && col < 100) { draw_char(page, col, *s++); col += 6; }
// }

// /* --------------------- LCD initialisation (EA sample) --------------------- */
// static void lcd_init(void)
// {
//     /* GPIO for DC & RST */
//     gpio_config_t g = {.mode = GPIO_MODE_OUTPUT,
//                        .pin_bit_mask = (1ULL << LCD_DC) | (1ULL << LCD_RST)};
//     gpio_config(&g);

//     /* Reset pulse */
//     gpio_set_level(LCD_RST, 0);
//     vTaskDelay(pdMS_TO_TICKS(5));
//     gpio_set_level(LCD_RST, 1);

//     /* SPI bus @ 2 MHz (safe) */
//     spi_bus_config_t bus = {
//         .mosi_io_num = LCD_MOSI,
//         .miso_io_num = -1,
//         .sclk_io_num = LCD_SCLK,
//         .max_transfer_sz = 128
//     };  
//     spi_bus_initialize(LCD_SPI_HOST, &bus, SPI_DMA_CH_AUTO);

//     spi_device_interface_config_t dev = {
//         .clock_speed_hz = 2 * 1000 * 1000,
//         .mode = 0,
//         .spics_io_num = LCD_CS,
//         .queue_size = 4
//     };
//     spi_bus_add_device(LCD_SPI_HOST, &dev, &lcd);

//     /* EA‑DOGS104 power‑up sequence */
//     const uint8_t seq[] = {
//         0x3A, 0x09, 0x06, 0x1E,
//         0x39, 0x1B, 0x6E, 0x56, 0x7A,
//         0x38
//     };
//     for (size_t i = 0; i < sizeof(seq); i++) lcd_cmd(seq[i]);

//     lcd_cmd(0x0F);      /* display ON, cursor/blink OFF */
//     lcd_clear();
// }


/* -------------------------------------------------------------------------- */
/*  Wi‑Fi helper (event‑group & handler)                                      */
/* -------------------------------------------------------------------------- */
static EventGroupHandle_t wifi_event_group;
#define WIFI_CONNECTED_BIT BIT0

static void wifi_event_handler(void *arg,
                               esp_event_base_t event_base,
                               int32_t event_id,
                               void *event_data)
{
    if (event_base == WIFI_EVENT && event_id == WIFI_EVENT_STA_START) {
        esp_wifi_connect();
    } else if (event_base == WIFI_EVENT && event_id == WIFI_EVENT_STA_DISCONNECTED) {
        ESP_LOGW(TAG, "Wi‑Fi disconnected — retrying…");
        esp_wifi_connect();
    } else if (event_base == IP_EVENT && event_id == IP_EVENT_STA_GOT_IP) {
        xEventGroupSetBits(wifi_event_group, WIFI_CONNECTED_BIT);
        ip_event_got_ip_t *e = (ip_event_got_ip_t *)event_data;
        ESP_LOGI(TAG, "✅ Got IP: " IPSTR, IP2STR(&e->ip_info.ip));
    }
}

static void wifi_init_sta(void)
{
    wifi_event_group = xEventGroupCreate();

    ESP_ERROR_CHECK(esp_netif_init());
    ESP_ERROR_CHECK(esp_event_loop_create_default());
    esp_netif_create_default_wifi_sta();

    wifi_init_config_t cfg = WIFI_INIT_CONFIG_DEFAULT();
    ESP_ERROR_CHECK(esp_wifi_init(&cfg));
    ESP_ERROR_CHECK(esp_wifi_set_ps(WIFI_PS_NONE));          // keep RF on for TLS

    wifi_config_t sta_cfg = {
        .sta = {
            .ssid = WIFI_SSID,
            .password = WIFI_PASS,
            .threshold.authmode = WIFI_AUTH_WPA2_PSK,
            .pmf_cfg = {.capable = true, .required = false},
        }
    };

    ESP_ERROR_CHECK(esp_wifi_set_mode(WIFI_MODE_STA));
    ESP_ERROR_CHECK(esp_wifi_set_config(WIFI_IF_STA, &sta_cfg));

    ESP_ERROR_CHECK(esp_event_handler_instance_register(
                        WIFI_EVENT, ESP_EVENT_ANY_ID,
                        &wifi_event_handler, NULL, NULL));
    ESP_ERROR_CHECK(esp_event_handler_instance_register(
                        IP_EVENT, IP_EVENT_STA_GOT_IP,
                        &wifi_event_handler, NULL, NULL));

    ESP_ERROR_CHECK(esp_wifi_start());

    /* wait max 10 s until connected */
    EventBits_t bits = xEventGroupWaitBits(wifi_event_group,
                                           WIFI_CONNECTED_BIT,
                                           pdFALSE, pdFALSE,
                                           pdMS_TO_TICKS(10000));
    if (!(bits & WIFI_CONNECTED_BIT)) {
        ESP_LOGE(TAG, "❌ Wi‑Fi connection timed out");
    }
}

/* -------------------------------------------------------------------------- */
/*  GPIO helpers                                                              */
/* -------------------------------------------------------------------------- */
static void gpio_init_buttons(void)
{
    gpio_config_t io_conf = {
        .intr_type = GPIO_INTR_DISABLE,
        .mode = GPIO_MODE_INPUT,
        .pull_up_en = GPIO_PULLUP_ENABLE,
        .pin_bit_mask = (1ULL << BTN_A) | (1ULL << BTN_B) |
                        (1ULL << BTN_C) | (1ULL << BTN_D) |
                        (1ULL << BTN_E)
    };
    gpio_config(&io_conf);
}

static char detect_answer_button(void)
{
    if (!gpio_get_level(BTN_A)) return 'A';
    if (!gpio_get_level(BTN_B)) return 'B';
    if (!gpio_get_level(BTN_C)) return 'C';
    if (!gpio_get_level(BTN_D)) return 'D';
    if (!gpio_get_level(BTN_E)) return 'E';
    return 0;
}

/* -------------------------------------------------------------------------- */
/*  Firebase helpers                                                          */
/* -------------------------------------------------------------------------- */
static char *resp_buf   = NULL;
static size_t resp_cap  = 0;
static size_t resp_used = 0;

static esp_err_t http_evt(esp_http_client_event_t *evt)
{
    switch (evt->event_id) {
    case HTTP_EVENT_ON_DATA:
        if (!resp_buf) {                       // first chunk → allocate
            resp_cap  = evt->data_len + 1;
            resp_buf  = malloc(resp_cap);
            resp_used = 0;
        }
        /* grow the buffer if needed */
        while (resp_used + evt->data_len + 1 > resp_cap) {
            resp_cap *= 2;
            resp_buf  = realloc(resp_buf, resp_cap);
        }
        memcpy(resp_buf + resp_used, evt->data, evt->data_len);
        resp_used += evt->data_len;
        break;

    case HTTP_EVENT_ON_FINISH:
        if (resp_buf) resp_buf[resp_used] = 0; // NUL‑terminate
        break;
    default:
        break;
    }
    return ESP_OK;
}



static bool fetch_current_prompt(Prompt *prompt)
{
    esp_http_client_config_t cfg = {
        .url = FIREBASE_CURRENT_PROMPT,
        .transport_type = HTTP_TRANSPORT_OVER_SSL,
        .crt_bundle_attach = esp_crt_bundle_attach,   // ➌ verify with bundle
        .timeout_ms = 10000,
        .event_handler    = http_evt
    };

    resp_buf = NULL;   /* reset global scratch buffer */
    resp_cap = resp_used = 0;
    esp_http_client_handle_t client = esp_http_client_init(&cfg);

    esp_http_client_set_header(client, "Accept-Encoding", "identity");


    esp_err_t err = esp_http_client_perform(client);
    if (err != ESP_OK) {
        ESP_LOGE(TAG, "Failed to fetch prompt: %s", esp_err_to_name(err));
        esp_http_client_cleanup(client);
        return false;
    }

    int status = esp_http_client_get_status_code(client);
    ESP_LOGI(TAG, "HTTP status: %d", status);
    if (status != 200) {
        ESP_LOGE(TAG, "Unexpected status %d ‑ aborting", status);
        esp_http_client_cleanup(client);
        return false;
    }

    int len = esp_http_client_get_content_length(client);
    if (len <= 0) {
        ESP_LOGE(TAG, "Prompt length 0");
        esp_http_client_cleanup(client);
        return false;
    }

    

    ESP_ERROR_CHECK_WITHOUT_ABORT(esp_http_client_perform(client));

    if (!resp_buf || resp_used == 0) {
        ESP_LOGE(TAG, "Empty body");
        esp_http_client_cleanup(client);
        return false;
    }

    // ESP_LOGI(TAG, "Fetched JSON (%zu bytes): %s", resp_used, resp_buf);
    cJSON *json = cJSON_Parse(resp_buf);
    free(resp_buf);                        // done with the scratch buffer
    esp_http_client_cleanup(client);


    if (!json) {
        ESP_LOGE(TAG, "Prompt JSON parse error");
        return false;
    }

    strncpy(prompt->question, cJSON_GetObjectItem(json, "question")->valuestring, sizeof(prompt->question));
    strncpy(prompt->subject,  cJSON_GetObjectItem(json, "subject")->valuestring,  sizeof(prompt->subject));
    strncpy(prompt->correctAnswer, cJSON_GetObjectItem(json, "correctAnswer")->valuestring, sizeof(prompt->correctAnswer));

    cJSON_Delete(json);
    return true;
}

static void send_to_firebase(int emotion, char selectedAnswer)
{
    Prompt prompt;
    if (!fetch_current_prompt(&prompt)) {
        ESP_LOGW(TAG, "Using fallback prompt");
        strcpy(prompt.question, "Unknown");
        strcpy(prompt.subject,  "Unknown");
        strcpy(prompt.correctAnswer, "Z");
    }

    char url[256];
    snprintf(url, sizeof(url), FIREBASE_RESPONSES_PATH, STUDENT_ID);

    // time_t now; time(&now);

    cJSON *json = cJSON_CreateObject();
    // cJSON_AddNumberToObject(json, "timestamp", now);
    int64_t now_ms = (int64_t)time(NULL) * 1000;   // seconds → ms
    cJSON_AddNumberToObject(json, "timestamp", now_ms);

    cJSON_AddStringToObject(json, "rfid", RFID_TAG);
    cJSON_AddNumberToObject(json, "emotion", emotion);

    char answerStr[2] = { selectedAnswer, '\0' };
    cJSON_AddStringToObject(json, "selectedAnswer", answerStr);

    cJSON_AddStringToObject(json, "question", prompt.question);
    cJSON_AddStringToObject(json, "subject",  prompt.subject);
    cJSON_AddStringToObject(json, "correctAnswer", prompt.correctAnswer);
    cJSON_AddBoolToObject(json, "isCorrect", selectedAnswer == prompt.correctAnswer[0]);

    char *post_data = cJSON_PrintUnformatted(json);

    esp_http_client_config_t cfg = {
        .url = url,
        .transport_type = HTTP_TRANSPORT_OVER_SSL,
        .crt_bundle_attach = esp_crt_bundle_attach,   // ➌ verify with bundle
        .timeout_ms = 10000,
    };
    esp_http_client_handle_t client = esp_http_client_init(&cfg);
    esp_http_client_set_method(client, HTTP_METHOD_POST);
    esp_http_client_set_header(client, "Content-Type", "application/json");
    esp_http_client_set_post_field(client, post_data, strlen(post_data));

    esp_err_t err = esp_http_client_perform(client);
    if (err == ESP_OK) {
        ESP_LOGI(TAG, "✅ Data sent to Firebase.");
    } else {
        ESP_LOGE(TAG, "❌ Error sending data: %s", esp_err_to_name(err));
    }

    /* ✳ NEW – update LCD with latest values */
    // lcd_update_screen(STUDENT_NAME, selectedAnswer, emotion);

    esp_http_client_cleanup(client);
    cJSON_Delete(json);
    free(post_data);
}

/* -------------------------------------------------------------------------- */
/*  Main                                                                      */
/* -------------------------------------------------------------------------- */
void app_main(void)
{
    ESP_ERROR_CHECK(nvs_flash_init());

    // lcd_init();
    // lcd_set_contrast(0x23, 0x28);   // was 0x26 → try 0x28
    // draw_str(0, "Hello Ethan Ge");

    // /* -------- HAL pin mapping ---------- */
    // u8g2_esp32_hal_t cfg = U8G2_ESP32_HAL_DEFAULT;
    // cfg.bus.spi.clk   = PIN_SCLK;
    // cfg.bus.spi.mosi  = PIN_MOSI;
    // cfg.bus.spi.cs    = PIN_CS;
    // cfg.dc    = PIN_DC;
    // cfg.reset = PIN_RST;
    // u8g2_esp32_hal_init(cfg);

    // /* -------- Choose the right constructor ---------- *
    //  * UC1701 == controller used on EA-DOGS104-A.
    //  * The library has a ready-made setup for it:       */
    // u8g2_t u8g2;
    // u8g2_Setup_uc1701_ea_dogs102_f(
    //     &u8g2, U8G2_R0,                       // no rotation
    //     u8g2_esp32_spi_byte_cb,               // SPI byte callback
    //     u8g2_esp32_gpio_and_delay_cb);        // GPIO & delays

    // /* -------- Power-up sequence ---------- */
    // ESP_LOGI(LCD_TAG, "Init display");
    // u8g2_InitDisplay(&u8g2);      // sends the UC1701 init sequence
    // u8g2_SetPowerSave(&u8g2, 0);  // wake up
    // u8g2_ClearBuffer(&u8g2);

    // /* -------- Draw something ---------- */
    // // u8g2_SetFont(&u8g2, u8g2_font_6x10_tf);   // any built-in font
    // // u8g2_DrawStr(&u8g2, 0, 12, "Hello Ethan Ge");

    // u8g2_SetDrawColor(&u8g2, 1);                 // 1 = set pixels (black)
    // u8g2_DrawBox(&u8g2, 0, 0,                    // x, y
    // u8g2_GetDisplayWidth(&u8g2),    // full width  (104 px on DOGS104)
    // u8g2_GetDisplayHeight(&u8g2));  // full height ( 64 px)

    // /* -------- Send to LCD ---------- */
    // u8g2_SendBuffer(&u8g2);        // <= nothing shows until you call this!

    /* done */
    // vTaskDelete(NULL);

    wifi_init_sta();                       // returns after IP ready
    obtain_time();            // blocks until time acquired
    gpio_init_buttons();

    adc1_config_width(ADC_WIDTH_BIT_12);
    adc1_config_channel_atten(POT_CHANNEL, ADC_ATTEN_DB_11);

    gpio_num_t pot_gpio;
    if (adc1_pad_get_io_num(POT_CHANNEL, &pot_gpio) == ESP_OK) {
        ESP_LOGI(TAG, "Reading potentiometer on GPIO%d (ADC1_CH%d)", pot_gpio, POT_CHANNEL);
    } else {
        ESP_LOGE(TAG, "adc1_pad_get_io_num failed");
    }


    // or poll buttons continuously
    while (1) {
        char ans = detect_answer_button();
        if (ans) {
            // int emotion = 5;  // read potentiometer here

            

            int raw = adc1_get_raw(POT_CHANNEL);

            // 2) map to 1–10
            // raw: 0…4095 → mapped: 0…9
            int mapped = (raw * 10) / 4096; 
            // invert so 0→10, 9→1
            int emotion = 10 - mapped;
            // clamp just in case
            if      (emotion < 1)  emotion = 1;
            else if (emotion > 10) emotion = 10;
            ESP_LOGI(TAG, "Raw Pot Value %d", raw);

            ESP_LOGI(TAG, "RFID: %s | Answer: %c | Emotion: %d", RFID_TAG, ans, emotion);
            send_to_firebase(emotion, ans);

            vTaskDelay(pdMS_TO_TICKS(2000));
        } else {
            vTaskDelay(pdMS_TO_TICKS(100));
        }
    }
    
}

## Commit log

2025-04-03 Prototype webapp using dummy data
2025-04-23 buttons and pot working
